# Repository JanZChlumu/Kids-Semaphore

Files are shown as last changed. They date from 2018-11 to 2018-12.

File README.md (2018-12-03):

# Semaphore with IR remote controler
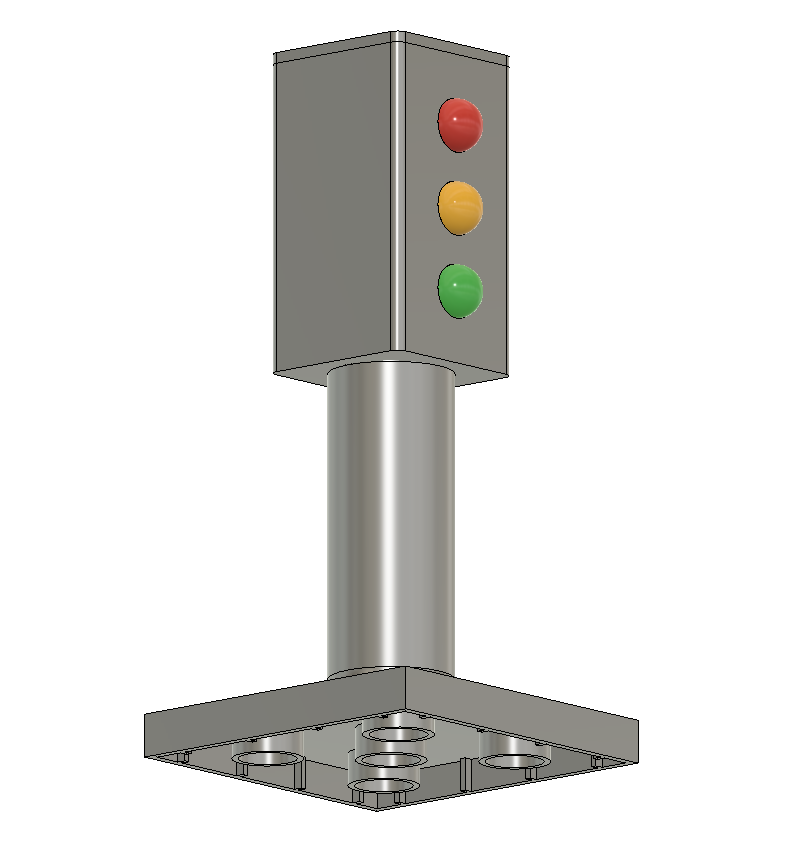
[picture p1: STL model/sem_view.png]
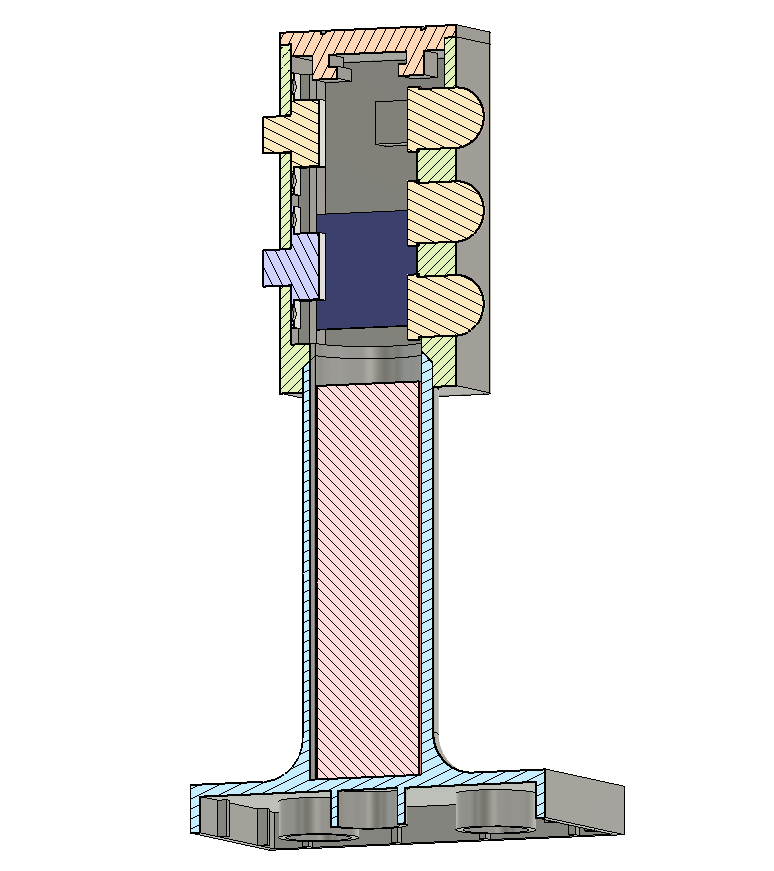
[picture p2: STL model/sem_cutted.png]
cutout

[Demonstration video (YouTube)](https://youtu.be/u1l54P9FhmE)

**Motivation**: create toy for 2 years child for increasing knowlage about behavior on crossroads :)

## Description:
Semaphore leg is designed to be LEGO Duplo compatible. It could be connected with bricks.

Toy has 2 modes:

- **Manual**: By touching the cover, colours are changed.
- **IR mode**: Semaphore is driven by receiving signals from remote controller. It is used IR Tx joystick from this toy [ **Train with remote IR control**](https://www.lidl-shop.cz/PLAYTIVE-JUNIOR-Vlacek-na-dalkove-ovladani/p100246613)

### Manual control
Is really simple to chang states by touching semaphore head: Stop (red) -> Ready (orange) -> Go (green) -> Prepare for stop (red+orange).

### IR control description
Arduino library was used for deconding IR [IRLremote](https://github.com/NicoHood/IRLremote/blob/master/Readme.md) in mode _CHashIR_. Joystick transmitter has not standard Tx format, that means, _with different libraries, differend results will be obtained_. It's recomended to test receiveing data with your transmitter. For this situation is designed macro for debug
```cpp
#define DEBUG //Comment this for stop debuging
```
Joystick has two modes A or B with different transmited data. Lever has 4 states. 
- UP
  - Tip position (stop the train)
  - Hold long (run the train)
- DOWN
  - Tip position (stop the train)
  - Hold long (run the train)
  
 With given library was received folowing datagrams. 

**Mode A**

|Rx data|UP tip	 |UP long |	DOWN tip  |	DOWN long |
| --- | --- | --- | --- | --- |
|0 |0x90B1027A|**0x90B1027A**	|0x20E9B7A|**0x20E9B7A**|
|1 |**0xFF7A3B7A**|**0x90B1027A**	|**0xFF7A3B7A**|**0x20E9B7A**|
|2 |**0xFF7A3B7A**|**0x90B1027A**	|**0xFF7A3B7A**|**0x20E9B7A**|
|3 |**0xFF7A3B7A**| |**0xFF7A3B7A**|	

**Mode B**

|Rx data|UP tip	 |UP long |	DOWN tip  |	DOWN long |
| --- | --- | --- | --- | --- |
|0 |0xC4EF317A |**0xC4EF317A**|	 0x364CCA7A|	**0x364CCA7A**|
|1 |**0x33B86A7A**|**0xC4EF317A**|	**0x33B86A7A**| **0x364CCA7A**|
|2 |**0x33B86A7A**|**0xC4EF317A**|	**0x33B86A7A**|	**0x364CCA7A**|
|3 |**0x33B86A7A**| | **0x33B86A7A**|	 |

When we look on data we'll see that the best solution how to decode position is read last 3 data datagrams (bold in tables).
The relevant joystick lever combinations are stored in:
```cpp
/*commands received from joystick*/
const HashIR_command_t IrRxCommnad[2][4] = {  //[command],[transmitter mode A/B]
    //  { mode A UP,  mode A DOWN,    mode B UP,   mode B DOWN}
  	{0xFF7A3B7A,   0xFF7A3B7A,   0x33B86A7A,   0x33B86A7A},   /*Go2Stop (all TIP positions)*/
	{0x90B1027A,    0x20E9B7A,   0xC4EF317A,   0x364CCA7A}};  /*Go2Run (all long hold positions)*/
```
### Battery & discharging
Used charger is little bit stupid and doesn't solve problem with deep discharge. That's why indication function was implemented. When Lion battery reach 3,1V all semaphore functions are deactivate only orange LED is cyclicaly blinking (like in real situation - when traffic lights are out of order) and 15 minutes power off mode is activated.

Other case is when child forgot on the toy for 15 minutes, semaphore goes over sleep mode. 

Minimum power consumption for bought situations is 250uA.
For increasing low power consumption was removed [LDO regulator](http://ww1.microchip.com/downloads/en/DeviceDoc/20005785A.pdf), power on LED from Arduino Mini, IR sensor and capapity button is disconned form power supply ( see [schematic](https://github.com/JanZChlumu/Kids-Semaphore/blob/master/miscellaneous/Semaphore_schematic.pdf)). 
## Compilation
Project was setup for Eclipse with arduino plugin. Last [hex](https://github.com/JanZChlumu/Kids-Semaphore/blob/master/Semaphore/Release/Semaphore.hex) file is stored in project.
## Semaphore parts
* [Lipol charger](https://www.electroschematics.com/10551/tp4056-lipo-battery-charger-rc-toys/)
* [Arduino mini](https://www.aliexpress.com/item/ATMEGA328P-Pro-Mini-328-Mini-ATMEGA328-5V-16MHz-5V-16M-for-arduino/32831029894.html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), [schema](https://cdn.sparkfun.com/datasheets/Dev/Arduino/Boards/Arduino-Pro-Mini-v14.pdf)
* [Capacity button](https://www.aliexpress.com/item/TTP223-Module-Capacitive-Touch-Switch-Button-Self-Lock-Key-Module-2-5-5-5V/32709015595.html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)
* [IR module](https://www.tme.eu/cz/Document/c26cc9aca2ad933c9d4bdc84e43ef900/TSOP2238.pdf)
* [Switch](https://www.tme.eu/cz/details/s1501/posuvne-prepinace/)
* [LEDs](https://www.tme.eu/cz/Document/01421dc8dab8fa585126521a0ba7da49/OSXXXXA1K4A.pdf)
* Battery 18650 (inserted in leg)
* [STL models (see STL model)](https://www.thingiverse.com/thing:3239892)

## Other links
* [Schematic](https://github.com/JanZChlumu/Kids-Semaphore/blob/master/miscellaneous/Semaphore_schematic.pdf)
* [Final product picture](https://github.com/JanZChlumu/Kids-Semaphore/blob/master/miscellaneous/finished_set.jpg)

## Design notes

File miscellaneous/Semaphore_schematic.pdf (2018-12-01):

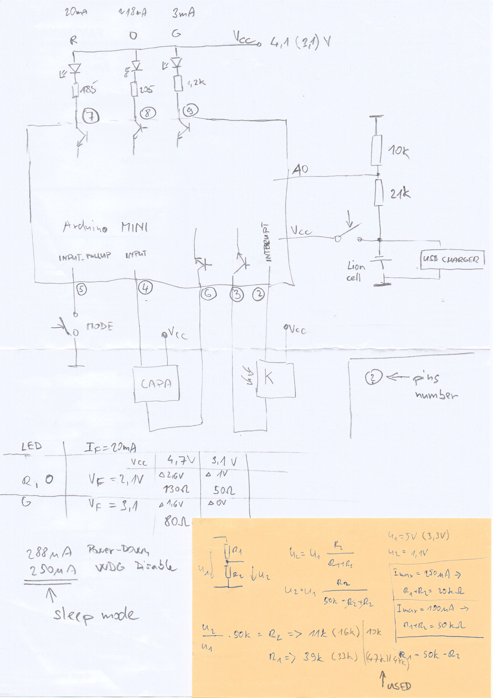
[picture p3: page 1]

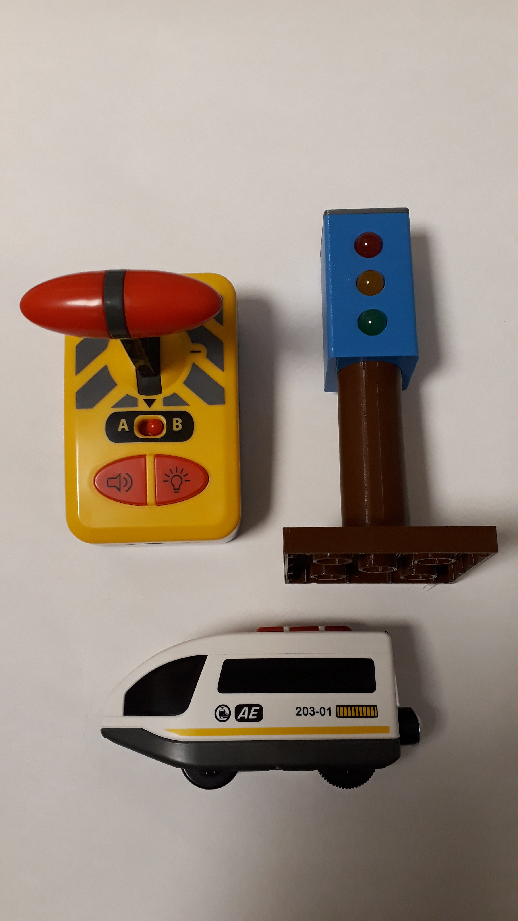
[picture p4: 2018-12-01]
miscellaneous/finished_set.jpg

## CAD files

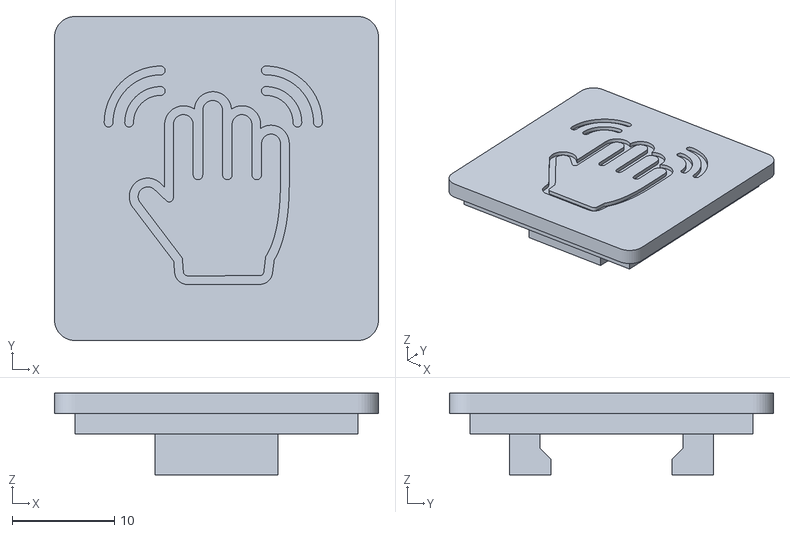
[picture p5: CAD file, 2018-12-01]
STL model/Sem_cover45.stl
31.7 x 31.7 x 8.00

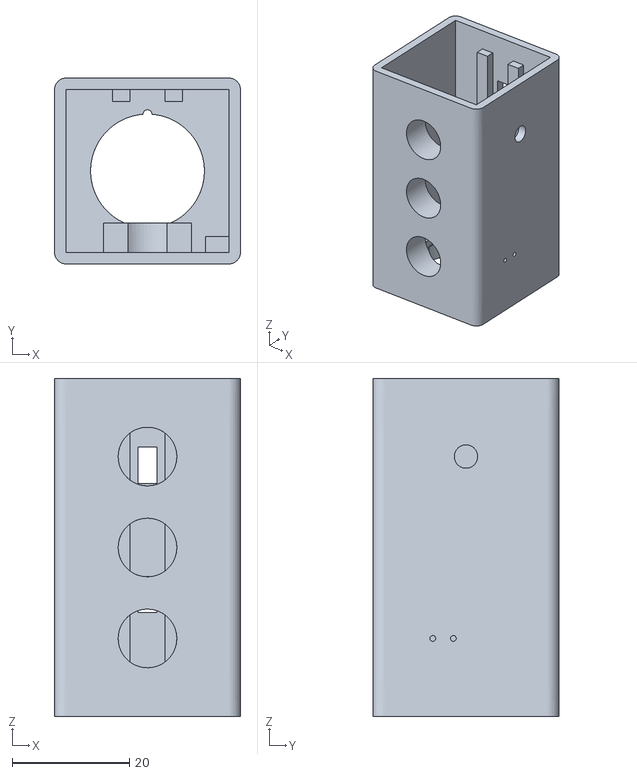
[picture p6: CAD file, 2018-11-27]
STL model/Sem_head.stl
31.7 x 31.7 x 57.6

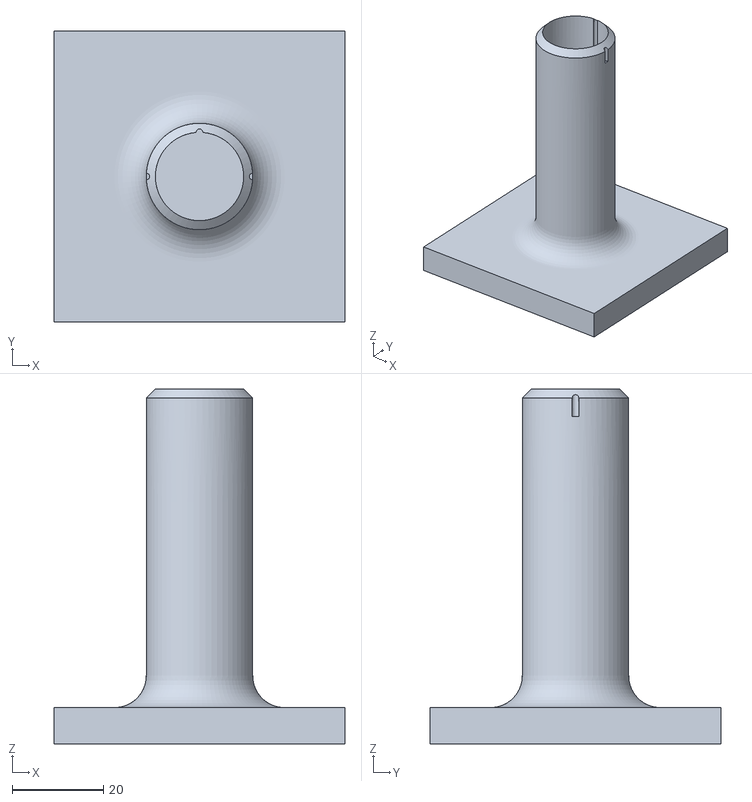
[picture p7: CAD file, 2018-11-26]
STL model/Sem_leg.stl
63.9 x 63.9 x 78.0

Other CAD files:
STL model/Sem_cover.stl

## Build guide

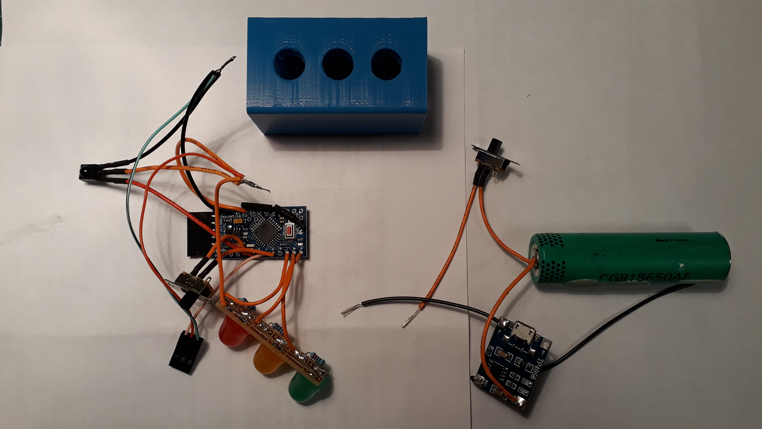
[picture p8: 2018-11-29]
miscellaneous/before assemble.jpg

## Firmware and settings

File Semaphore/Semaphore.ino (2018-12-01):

/*
  Semaphore toy

  The following pins are usable for PinInterrupt or PinChangeInterrupt*:
  Arduino Uno/Nano/Mini: 2, 3, All pins* are usable

IR libraly reference manual
https://github.com/NicoHood/IRLremote/blob/master/Readme.md
*/

#include "IRLremote.h"
#include "SemaphoreTypes.h"
#include <avr/sleep.h>
#include <avr/wdt.h>

/* if DEBUG is used some IR Rx data could not be captured*/
//#define DEBUG //Comment this for stop debuging
#ifdef DEBUG
	#define PRINT(x) Serial.print(x)
	#define PRINTLN(x) Serial.println(x)

	/****** debug pins******/
	#define pinDeb1 10
	#define D1_ON  digitalWrite(pinDeb1,HIGH)
	#define D1_OFF digitalWrite(pinDeb1,LOW)

	#define pinDeb2 11
	#define D2_ON  digitalWrite(pinDeb2,HIGH)
	#define D2_OFF digitalWrite(pinDeb2,LOW)
	/*----* debug pins end -----*/

#else
	#define PRINT(x)
	#define PRINTLN(x)
	#define D1_ON
	#define D1_OFF
	#define D2_ON
	#define D2_OFF
#endif

/*LEDs pins*/
#define pinLedRed         7
#define pinLedOrange      8
#define pinLedGren	      9

/*Switches */
#define pinSwitchMode     5
#define pinBtnTouch 	  4

/*Power On components*/
#define pinBtnTouch_Power 6		//Capacity sensor
#define pinIR_Power 	  3		//IR sensor

/*IR sensor */
#define pinIR 2
CHashIR IRLremote;

#define analogPin 0

/* VARIABLES */
const unsigned long POWER_ON_TIMEOUT = 900000; //15minutes (15*60*1000)
volatile bool oldBtn = FALSE;
SemIRStates_T SemIRState = NotValid;
volatile unsigned long PowerOnTimeOut = 0ul;
volatile SemHumanControlSteps_T SemControl = Manual;
RxData_T RxData = {.dataIndex = 0, .RxBuffer = {0,1,2}};

/*commands received from joystick*/
const HashIR_command_t IrRxCommnad[2][4] = {  //[command],[transmitter mode A/B]
	//  { mode A UP,  mode A DOWN,    mode B UP,   mode B DOWN}
		{0xFF7A3B7A,   0xFF7A3B7A,   0x33B86A7A,   0x33B86A7A},   /*Go2Stop (all TIP positions)*/
		{0x90B1027A,    0x20E9B7A,   0xC4EF317A,   0x364CCA7A}};  /*Go2Run (all long hold positions)*/


/*Set semaphore color*/
void SetSemColor(SemColor_T color){

	/* Color change leads to trigger reset PowerTimeOut
	 * Under voltage lead to sleep mode in 15minutes*/
	if(SemControl != BatteryLow){
		PowerOnTimeOut = millis();
	}

	switch(color){
	case Red:
	    digitalWrite(pinLedRed	 , LOW);
	    digitalWrite(pinLedOrange, HIGH);
	    digitalWrite(pinLedGren  , HIGH);
		break;
	case Red_plus_Orange:
		digitalWrite(pinLedRed   , LOW);
		digitalWrite(pinLedOrange, LOW);
		digitalWrite(pinLedGren  , HIGH);
		break;
	case Green:
		digitalWrite(pinLedRed   , HIGH);
		digitalWrite(pinLedOrange, HIGH);
		digitalWrite(pinLedGren  , LOW);
		break;
	case Orange:
		digitalWrite(pinLedRed   , HIGH);
		digitalWrite(pinLedOrange, LOW);
		digitalWrite(pinLedGren  , HIGH);
		break;
	default:
		digitalWrite(pinLedRed   , HIGH);
		digitalWrite(pinLedOrange, HIGH);
		digitalWrite(pinLedGren  , HIGH);
		break;
	}
}

void SemManualStepIncrease(void){
	static unsigned char step = 0;

	if(step < ((unsigned char)No_light - 1)){
		step++;
	}else{
		step = 0;
	}
	SetSemColor((SemColor_T)step);
	PRINT(F("Man_Step: "));
	PRINTLN(step);
}

#define arrayAvrSize  15   //used for average value
/* after power on function slowly integrated to actual voltage value
 * could not be activated often - affect IR reading*/
// time consumption of this function 140us
unsigned int AverageVoltage(void){
	static int index = 0;
	static int array[arrayAvrSize] = { 1023, 1023, 1023, 1023, 1023, 1023, 1023, 1023, 1023, 1023, 1023, 1023, 1023, 1023, 1023 };
	static unsigned long oldTime = 0ul;
	unsigned long actualTime = millis();
	int suma = 0u;
	static unsigned int retVal = 1023u;

	if(actualTime > (oldTime + 500u)){
		array[index] = analogRead(analogPin);

		if(index < arrayAvrSize)
		{
			index++;
		}else{
			index = 0;
		}
		oldTime = actualTime;
	
		for(int i = 0; i < arrayAvrSize; i++){
			suma = suma + array[i];
		}
		retVal = (suma/arrayAvrSize);
	}
//	PRINTLN(retVal);
	return retVal;
}

#define BATTERY_LOW_LEVEL 850   // measured (tested) constant. Approx. 3,1V on battery
void ReadControlSelection(void){
	static int oldRead = 0;
	int actualRead = digitalRead(pinSwitchMode);

#ifdef DEBUG
//	delay(100);
#endif

	/*no hysteresis used, it's just a toy :-) */
	if(AverageVoltage() > BATTERY_LOW_LEVEL) 	
	{
		if ((actualRead != oldRead) || (SemControl == BatteryLow)){
			PRINT(F("Switch "));
			PRINTLN(actualRead);
			if(actualRead == 0u){
				SemControl = IR2Manual;
			}else{
				SemControl = Manual2IR;
			}
			oldRead = actualRead;
		}
	}else
	{
		PRINTLN(F("Under voltage"));
		SemControl = BatteryLow;
	}
}
/**
 * Decode received data.
 * Precondition: three same data was received
 */
SemIRStates_T RxDecode(HashIR_command_t rxData){

	for(unsigned int option=0; option < 4; option++){

		if(rxData == IrRxCommnad[Go2Stop][option]){
			return Go2Stop;
			PRINTLN(F("Decode Go2Stop"));

		}else if(rxData == IrRxCommnad[Go2Run][option]){
			return Go2Run;
			PRINTLN(F("Decode Go2Run"));
		}
	}
	return NotValid;
}

/**
 * Change semaphore states when IR reception activated
 */
void SemIRStateMachine(SemIRStates_T * state){
	static unsigned long oldTime = 0;
	unsigned long actualTime = millis();
	static SemIRStates_T oldState = NotValid;

	switch(*state){
	case Go2Stop:
		if(oldState != Stop){
			oldTime = actualTime;
			SetSemColor(Orange);
			*state = Stop;
		}
		break;

	case Stop:
		if (actualTime > (oldTime + 500u)){
			SetSemColor(Red);
			oldState = Stop;
		}
		break;

	case Go2Run:
		if(oldState != Run){
			oldTime = actualTime;
			SetSemColor(Red_plus_Orange);
			*state = Run;
		}
		break;

	case Run:
		if (actualTime > (oldTime + 500u)){
			SetSemColor(Green);
			oldState = Run;
		}
		break;
	default:
		//SetSemColor(No_light);
		break;
	}
}
/**
 * Toy is not used for defined time. Better to go into deep sleep mode.
 * COULD BE LEAVE ONLY BY MECHANICAL SWITCH CYCLE
 * Current consumption in Power-save mode is 250uA //TODO some improvements?
 */
void PowerOnExpired(void){

	if(millis() > (PowerOnTimeOut + POWER_ON_TIMEOUT )){

		PRINTLN(F("Power OFF"));

		pinMode(pinLedRed, INPUT);
		pinMode(pinLedOrange, INPUT);
		pinMode(pinLedGren, INPUT);
		pinMode(pinSwitchMode,INPUT);
		pinMode(pinBtnTouch,INPUT);
		/*Power on components*/
		pinMode(pinBtnTouch_Power, INPUT);
		pinMode(pinIR_Power, INPUT);
#ifdef DEBUG
		pinMode(pinDeb1, INPUT);
		pinMode(pinDeb2, INPUT);
#endif
		wdt_disable();  					   // will save 38uA
 		detachInterrupt(0);      			   // disables interrupt 0 on pin 2 so the
		set_sleep_mode(SLEEP_MODE_PWR_DOWN);   // sleep mode is set here
	    sleep_mode();            			   // here the device is actually put to sleep!!
	}
}

void setup(){

	#ifdef DEBUG
	while (!Serial);
	Serial.begin(115200);
	PRINTLN(F("Startup"));

	pinMode(pinDeb1, OUTPUT);
	pinMode(pinDeb2, OUTPUT);
	D1_OFF;
	D2_OFF;
#endif

	pinMode(pinLedRed, OUTPUT);
	pinMode(pinLedOrange, OUTPUT);
	pinMode(pinLedGren, OUTPUT);
	pinMode(pinSwitchMode,INPUT_PULLUP);
	pinMode(pinBtnTouch,INPUT);

	/*Power on components*/
	pinMode(pinBtnTouch_Power, OUTPUT);
	digitalWrite(pinBtnTouch_Power, LOW);
	pinMode(pinIR_Power, OUTPUT);
	digitalWrite(pinIR_Power, LOW);

	SetSemColor(Orange);		//default color
	
	analogReference(INTERNAL);  //analog reference set to 1.1V

	PowerOnTimeOut = millis(); //trigger - reset PowerTimeOut
	ReadControlSelection();	
	PRINTLN(POWER_ON_TIMEOUT);
}



void loop (){
	bool actBtn  = FALSE;
	
	/*check how long was not semaphore used*/
	PowerOnExpired();
	
	switch(SemControl){

		/*Manual control*/
		case Manual:
			ReadControlSelection();			
			actBtn = digitalRead(pinBtnTouch);

			/*button has two state; touch, release. Only touch state is accessible */
			if(actBtn != oldBtn){
				if(actBtn == TRUE){
					SemManualStepIncrease();
					PRINT(F("T "));
				}else{
				}
				oldBtn = actBtn;
			}else
			{
			}
		break;
		
		/*Transition state; enable IR*/
		case Manual2IR:
			IRLremote.begin(pinIR); //TODO if error orange light
			SemControl = IR;
			digitalWrite(pinIR_Power, LOW);		//Power on
			delay(10);
		break;
		
		/* IR control */
		case IR:
			/*read IR data if available*/
			if (IRLremote.available()){
				D1_ON;
				HashIR_data_t rx_data = IRLremote.read();
				RxData.RxBuffer[RxData.dataIndex] = rx_data.command;

				PRINT(RxData.dataIndex);
				PRINT(F(" Rx "));
#ifdef DEBUG
				Serial.println(rx_data.command, HEX);
#endif
				/* cyclic filling buffer*/
				if(RxData.dataIndex < BUFFER_SIZE - 1){
					RxData.dataIndex++;
				}else{
					//buffer full
					RxData.dataIndex = 0 ;
				}
			}else{
				D1_OFF;
			}

			/*Timeout is triggered when IRLremote.available() == 1 , 20*1000 is physically 3,6ms after available data received
			 * this condition is entered always when nothing received*/
			if(IRLremote.timeout() > (20000)){
//				D2_ON;
				/*check if all 3 buffers are the same*/
				if((    RxData.RxBuffer[0] == RxData.RxBuffer[1])  \
					&& (RxData.RxBuffer[0] == RxData.RxBuffer[2])  ){

					/*Decode received data*/
					SemIRState = RxDecode(RxData.RxBuffer[0]);  //doesn't matter which index is hand over
					PRINT(F("Decode "));
					PRINTLN(SemIRState);

					/* "clear buffer" - write some absolutely unexpected data*/
					RxData.RxBuffer[0] = 0;
					RxData.RxBuffer[1] = 1;
					RxData.RxBuffer[2] = 2;
				}

				/*was received something now is some free time for other things...*/
				ReadControlSelection();
//				D2_OFF;
			}

			/*Call semaphore state machine*/
			SemIRStateMachine(&SemIRState);
		break;

		/*Transition state; disable IR*/
		case IR2Manual:
			IRLremote.end(pinIR);
			SemControl = Manual;
			digitalWrite(pinIR_Power, HIGH);		//Power OFF IR sensor (save some current consumption)
			delay(10);
		break;
		
		/* Battery low - semaphore error*/
		case BatteryLow:
			SetSemColor(Orange);
			delay(1000);
			SetSemColor(No_light);
			delay(1000);
			break;

		default:			
		break;					
	}
}

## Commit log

2018-11-26 STL model added
    [Sem_cover.stl, Sem_head.stl, Sem_leg.stl]
2018-11-27 LED and charge holder added
    [Sem_head.stl]
2018-11-29 Battery testing
2018-11-30 ADC modification
    faster voltage reading evaluation
